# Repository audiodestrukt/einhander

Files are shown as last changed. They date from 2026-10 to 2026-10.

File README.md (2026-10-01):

# einhander

A one-handed hardware controller for music performance and sequencing — MC-303-inspired,
simplicity-first. Two rows of four key switches under the fingers, a thumbwheel + SHIFT on
the side for the thumb, so the other hand stays free for sliders/faders.

This repo holds the **code-driven** design: a parametric enclosure (build123d) and a
fabbable PCB (tscircuit → KiCad).

einhander enclosure — isometric render

## What's here

```
cad/    parametric enclosure — build123d (machine_params.py = single source of truth),
        top/bottom shells + component stand-ins, assembly + dated render log
pcb/    RP2040 USB-MIDI controller board
          index.circuit.tsx        composes the board (flat, global nets)
          modules/                 mcu (RP2040+flash+xtal+decoupling), power (USB-C+LDO)
          lib/, imports/           shared params, custom Cherry-MX footprint, JLC parts
          scripts/                 route4.sh + the 4-layer routing toolchain
          index.circuit.kicad_pcb  routed 4-layer board
          fab/                     Gerbers + drill + CPL  (einhander-gerbers.zip → upload to JLCPCB)
pcb-rerun/  the same board re-routed unattended (2026-10-01) — 0 shorts, 2 open nets;
            found the DSN mirror bug behind pcb/'s hand patches (see pcb-rerun/README.md)
```

## The board

- **RP2040**, pure **USB-MIDI** controller (class-compliant, no drivers), wired USB-C
- 8 MX key switches on direct GPIO; EC11 thumbwheel + SHIFT broken out to a header for a
  left-wall daughterboard; one WS2812 status LED; BOOTSEL/RESET
- **4-layer**: signals on outer layers, dedicated **GND + 3V3 inner planes**
- **DRC-clean**, ~91 × 68 mm

Routed 4-layer PCB

Populated board (PCBA) with Cherry MX switches

Interactive 3D model of the populated board: **`pcb/renders/einhander-pcba.glb`** (open in any glTF viewer — Blender, VS Code glTF, or https://gltf-viewer.donmccurdy.com).

### Fabricating it

Upload `pcb/fab/einhander-gerbers.zip` to [JLCPCB](https://jlcpcb.com) (select **4 layers**). For
assembly, add `pcb/fab/einhander-bom.csv` (27 SMD parts, LCSC-mapped) + `pcb/fab/einhander-cpl.csv`
(placement). MX switches, the EC11 thumbwheel, headers, and BOOT/RESET tactiles are **hand-soldered**
(listed separately in `einhander-handsolder.csv`, kept out of the assembly BOM).

**PCBWay** uses the same `einhander-gerbers.zip` + `einhander-cpl.csv`, with `einhander-bom-pcbway.csv`
(sources by manufacturer part number instead of LCSC). `make_fab.sh` emits both BOM formats. Regenerate the whole bundle with `bash pcb/scripts/make_fab.sh pcb/index.circuit.kicad_pcb einhander`.

### Regenerating

```bash
# enclosure
cd cad && python3 machine.py            # STLs + renders

# PCB (needs bun/tscircuit, KiCad 9, Freerouting v2.2.4 + JDK 25)
cd pcb && npm install
bash scripts/route4.sh                  # export → route (4-layer) → inject → DRC
```

## Status

Enclosure prototype ✅ · Routed 4-layer PCB ✅ (fab-ready) · thumb-cluster daughterboard, RP2040
firmware (TinyUSB MIDI), and an enclosure↔board fit re-sync are next.

---
Designed with [Claude Code](https://claude.com/claude-code).

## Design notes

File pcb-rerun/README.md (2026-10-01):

# pcb-rerun — einhander re-routed unattended (2026-10-01)

A side-by-side re-run of the PCB pipeline next to the shipped board in [`../pcb`](../pcb). Same
circuit (`index.circuit.tsx` + `modules/` are unchanged), routed with **nobody touching it**, to
measure how close the code-driven pipeline gets on its own. Write-up:
[punkfab.com/blog/einhander-reroute](https://punkfab.com/blog/einhander-reroute/).

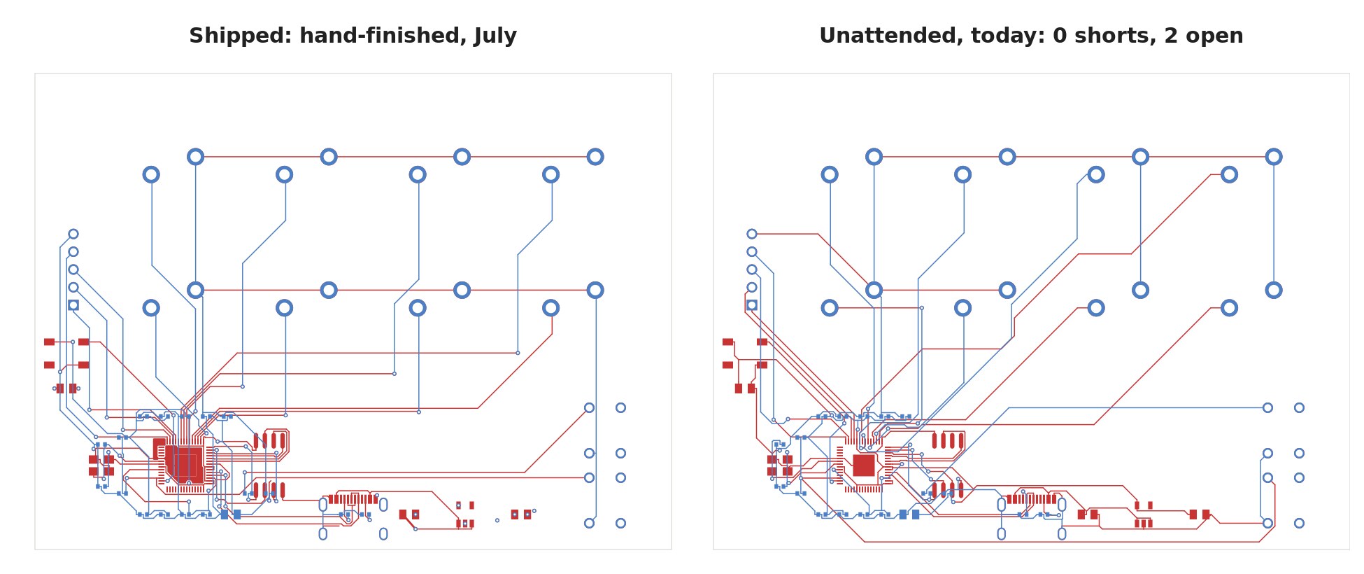
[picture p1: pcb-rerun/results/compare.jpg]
shipped vs unattended


## Result

| | Shipped (`../pcb`, July, hand-finished) | Unattended, raw | Unattended + `dsn_split_sides` |
|---|---|---|---|
| Shorts | 0 | 1 | **0** |
| Unconnected | 0 | 6 | **2** |
| Dangling tracks | 2 | 3 | **0** |
| Board-specific patch scripts | 3 | — | **0** |
| Track length | 1464 mm | 1461 mm | 1421 mm |
| Vias | 49 | 35 | 32 |

**Not fabbable yet** — two nets are open (QSPI_SCLK, one USB_DP pad). Use `../pcb` for fab.

## What was wrong

tscircuit's Specctra DSN export dedupes footprint images by name. C11 (0805, **bottom** side)
defined the shared 0805 image, so top-side C_IN / C_OUT / C_LED were handed to Freerouting as
mirrored bottom-side parts. Every short/open in the raw run was on those three parts — the
"dense LDO corner" that `../pcb/scripts/fix_ldo_planes.py` and `patch_stragglers.py` hand-patched.

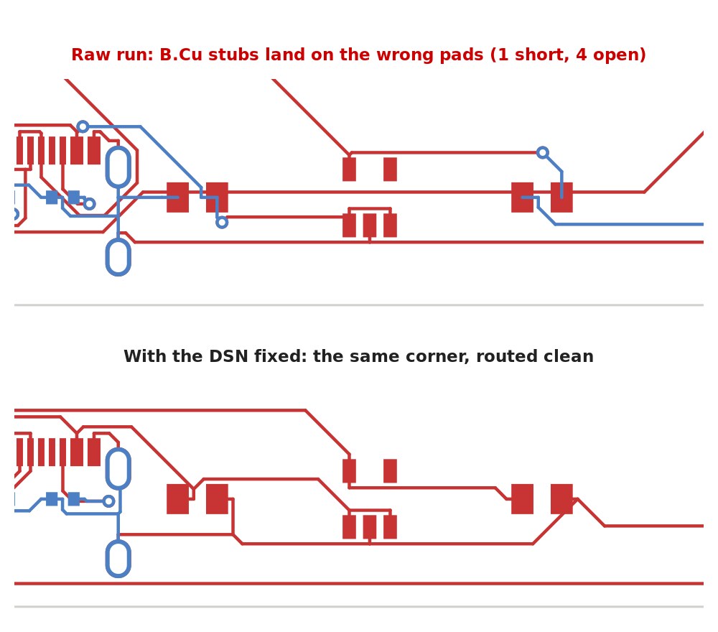
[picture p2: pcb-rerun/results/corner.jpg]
regulator corner, raw vs fixed


## What changed vs `../pcb`

- `scripts/dsn_split_sides.py` (new, wired into `route4.sh` step 2a) — rebuilds DSN images for any
  part whose pins disagree with the KiCad pads, compared in absolute board coordinates.
- `scripts/drc_check.py` — unconnected items now count as blocking (it printed `CLEAN` with open nets).
- `scripts/board_metrics.py` (new) — track length / segments / vias / zones for a `.kicad_pcb`.
- `scripts/dsn_freeze_ses.py` — **dead end**, kept as a record: freezing the routed SES as fixed DSN
  wiring for a tail-only second pass stalls Freerouting 2.2.4.
- `index.circuit.kicad_pcb` is the unattended + fix result (= `results/stage1-with-split-fix.kicad_pcb`).
- `fab/` and `renders/` were left out — they belong to the shipped board.

All of these are also in the `pcb-layout` skill:
[punkfab/circuit-skills](https://github.com/punkfab/circuit-skills).

## Reproduce

```bash
cd pcb-rerun
npm install                                   # tscircuit CLI (node_modules not committed)
DISPLAY=:0 bash scripts/route4.sh             # ~30 s: export -> DSN prep -> freert224 -> KiCad IPC -> DRC
/usr/bin/python3 scripts/board_metrics.py index.circuit.kicad_pcb
```

Needs the same toolchain as `../pcb`: bun/tsci, Freerouting 2.2.4 + JDK 25 (`freert224`), KiCad 9
with the IPC API (`kipy`), and system python with `pcbnew`.

## results/

| file | what |
|---|---|
| `stage0-raw-autorun.kicad_pcb`, `stage0-drc.json`, `stage0-metrics.json` | unattended run before the fix |
| `stage1-with-split-fix.kicad_pcb`, `stage1-drc.json`, `stage1-metrics.json` | unattended run with `dsn_split_sides.py` |
| `shipped-metrics.json` | the same metrics for `../pcb/index.circuit.kicad_pcb` |
| `compare.jpg`, `corner.jpg` | the figures from the blog post (KiCad F.Cu/B.Cu plots) |

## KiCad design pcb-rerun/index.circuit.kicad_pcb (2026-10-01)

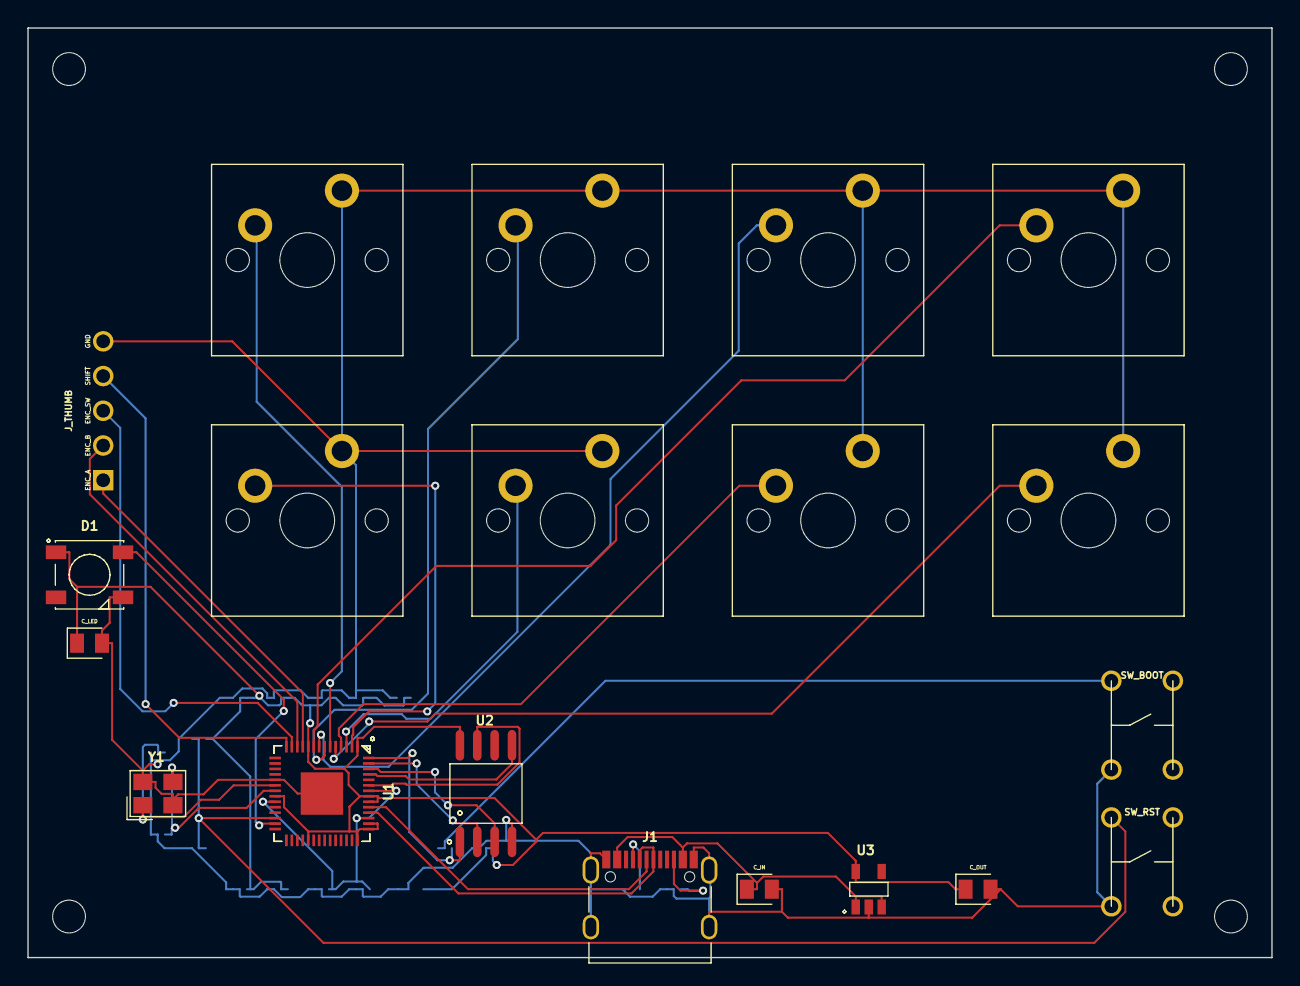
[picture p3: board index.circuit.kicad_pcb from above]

Board: 4 copper layers, 91.0 x 68.0 mm, 38 parts (0 on the bottom side), 31 nets.

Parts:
C1, C2, C3, C4, C5, C6, C7, C10, C14, C15: 100nF; capacitor_0402
C9: 1uF; capacitor_0402
C11: 10uF; capacitor_0805
C12, C13: 15pF; capacitor_0402
C_IN: 1uF; capacitor_0805
C_LED: 100nF; capacitor_0805
C_OUT: 1uF; capacitor_0805
D1: WS2812B_B_T
J1: TYPE_C_31_M_12
J_THUMB: J_THUMB; pin_header_pinrow5
R_BOOT: 1kΩ; resistor_res0402
R_CC1, R_CC2: 5.1kΩ; resistor_res0402
R_RUN: 10kΩ; resistor_res0402
SW1, SW2, SW3, SW4, SW5, SW6, SW7, SW8: chip
SW_BOOT: SW_BOOT; push_button_pushbutton
SW_RST: SW_RST; push_button_pushbutton
U1: RP2040
U2: W25Q16JVSSIQ
U3: AP2112K_3_3TRG1
Y1: X322512MSB4SI

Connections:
BOOT_BTN: R_BOOT.2, SW_BOOT.1
DVDD: C9.1, C10.1, U1.23, U1.45, U1.50
ENC_A: J_THUMB.1, U1.11
ENC_B: J_THUMB.2, U1.12
ENC_SW: J_THUMB.3, U1.13
GND: C1.2, C2.2, C3.2, C4.2, C5.2, C6.2, C7.2, C9.2, C10.2, C11.2, C12.2, C13.2, C14.2, C15.2, C_IN.2, C_LED.2, C_OUT.2, D1.3, J1.1, J1.2, J1.3, J1.4, J1.13, J1.14, J_THUMB.5, R_CC1.2, R_CC2.2, SW1.2, SW2.2, SW3.2, SW4.2, SW5.2, SW6.2, SW7.2, SW8.2, SW_BOOT.2, SW_RST.2, U1.19, U1.57, U2.4, U3.2, Y1.2, Y1.4
J1.A5 to R_CC1.pin1: J1.6, R_CC1.1
J1.B5 to R_CC2.pin1: J1.12, R_CC2.1
KEY0: SW1.1, U1.2
KEY1: SW2.1, U1.3
KEY2: SW3.1, U1.4
KEY3: SW4.1, U1.5
KEY4: SW5.1, U1.6
KEY5: SW6.1, U1.7
KEY6: SW7.1, U1.8
KEY7: SW8.1, U1.9
LED_DIN: D1.4, U1.27
QSPI_SCLK: U1.52, U2.6
QSPI_SD0: U1.53, U2.5
QSPI_SD1: U1.55, U2.2
QSPI_SD2: U1.54, U2.3
QSPI_SD3: U1.51, U2.7
QSPI_SS: R_BOOT.1, U1.56, U2.1
RUN: C14.1, R_RUN.2, SW_RST.1, U1.26
SHIFT: J_THUMB.4, U1.14
USB_DM: J1.7, J1.9, U1.46
USB_DP: J1.8, J1.10, U1.47
V3V3: C1.1, C2.1, C3.1, C4.1, C5.1, C6.1, C7.1, C11.1, C15.1, C_LED.1, C_OUT.1, D1.1, R_RUN.1, U1.1, U1.10, U1.22, U1.33, U1.42, U1.43, U1.44, U1.48, U1.49, U2.8, U3.5
VBUS: C_IN.1, J1.15, J1.16, U3.1, U3.3
XIN: C12.1, U1.20, Y1.1
XOUT: C13.1, U1.21, Y1.3
